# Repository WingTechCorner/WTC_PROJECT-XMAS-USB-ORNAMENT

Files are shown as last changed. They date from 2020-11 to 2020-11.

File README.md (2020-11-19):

# Wing's XMAS Ornament

** ISSUE - Design Seems To produce non-working unit. Investigating... **

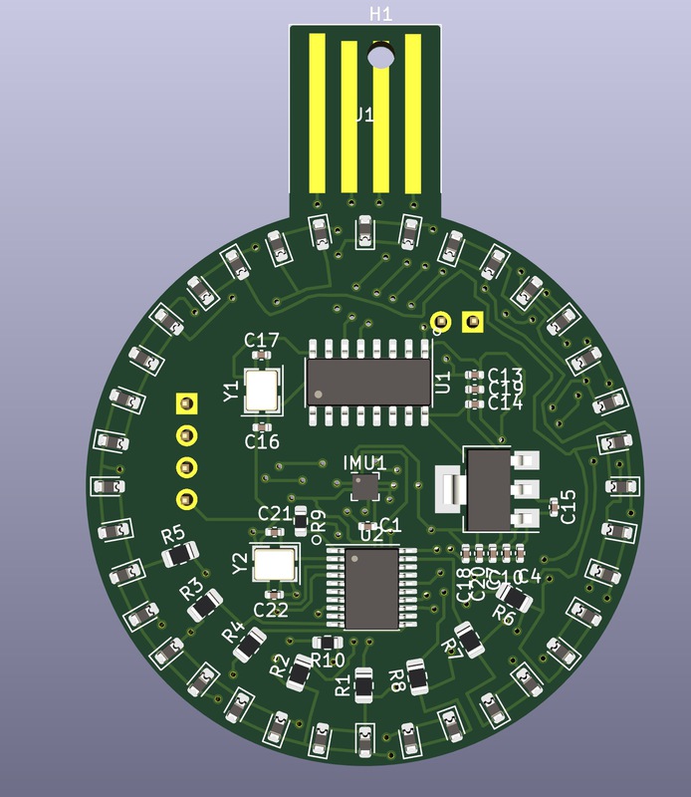
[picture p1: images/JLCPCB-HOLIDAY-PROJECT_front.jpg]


* Something for the holidays.
* Made using SMT/SMD components so most/all parts on one side.
* Added header pins on revrse side for adding batteries or different UART(s).
* Added USB-A PCB top to allow plugging into a laptop or computer USB port or to power with a USB-A extension cable.

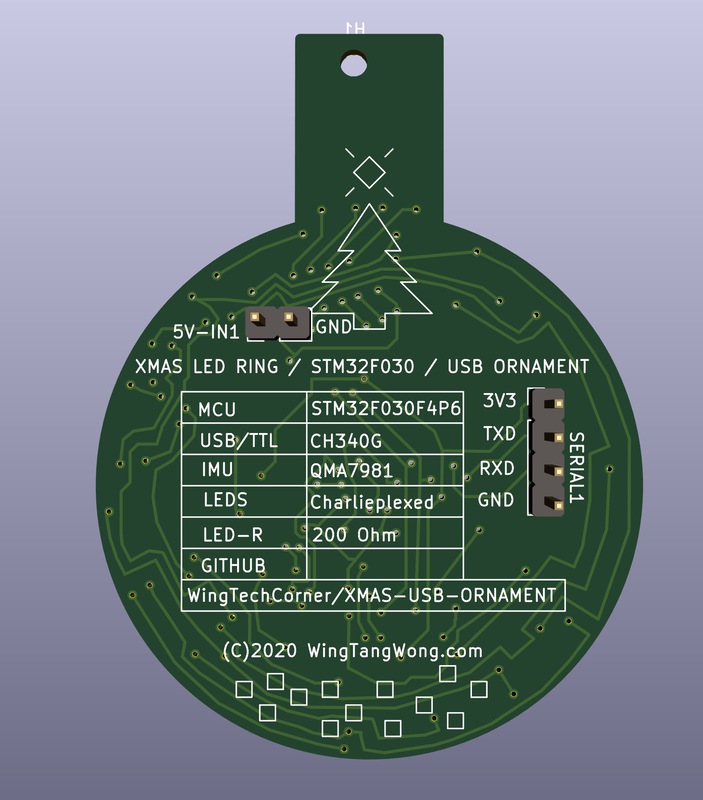
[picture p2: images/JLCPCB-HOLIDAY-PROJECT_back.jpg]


# JLCPCB Holiday Contest Entry

This is a project I'm also submitting to the [JLCPCB.com](http://www.jlcpcb.com) Holiday Contest!

* http://www.jlcpcb.com

# Hardware

## Components

* CH340G USB-to-TTL interface chip
* AMS1117-3v3 linear voltage regulator
* QMA7981 IMU in I2C mode
* STM32F030F4 - Arm M0 MCU

## STM32 

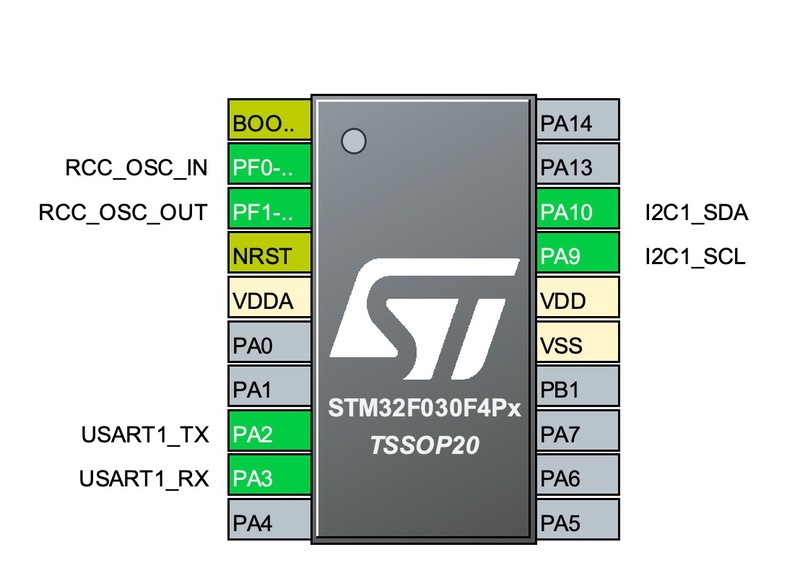
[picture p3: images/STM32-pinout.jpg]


* 12Mhz External OSC
* Boot0 - CH340G's CTS (pin 9) (pulldown via 4.7K, but can be brought HIGH by CH340G by toggling CTS)

### I2C 

* PA9  - I2C SCL (connects to QMA7981's SCL)
* PA10 - I2C SDA (connects to QMA7981's SDX)
* PB1  - Motion Interrupt Signal ( connects to QMA7981's INT2 )

### UART

* PA2  - UART-TX (connects to CH340G's RX)
* PA3  - UART-RD (connects to CH340G's TX)

### LED Driving Lines

* PA0  - A (CharliePlexed LED Lines)
* PA1  - B (CharliePlexed LED Lines)
* PA4  - C (CharliePlexed LED Lines)
* PA5  - D (CharliePlexed LED Lines)
* PA6  - E (CharliePlexed LED Lines)
* PA7  - F (CharliePlexed LED Lines)
* PA13 - G (CharliePlexed LED Lines)
* PA14 - H (CharliePlexed LED Lines)

## QMA7981

* AD0  - Sets address. Routed to GND for 0. 0x12H
* INT2 - Interrupt signal output. Routed to PB1 on MCU

## CH340G

* TXD  - To MCU RXD
* RXD  - To MCU TXD
* CTS  - To MCU BOOT0 for boot mode selector
* 12Mhz External OSC

# Software

## Building & Installing Arduino Code
The code is setup as a `platformio` project. To build:

```bash
# To compile/build
pio run

# To upload (Note, assumes serial upload)
pio run --target=upload
```

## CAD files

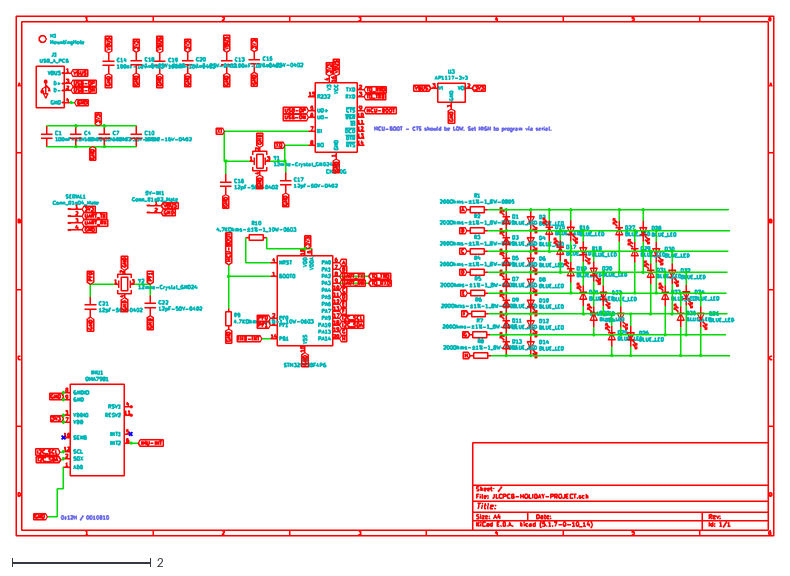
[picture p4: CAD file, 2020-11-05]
Hardware/JLCPCB-HOLIDAY-PROJECT.dxf
10.9 x 7.48

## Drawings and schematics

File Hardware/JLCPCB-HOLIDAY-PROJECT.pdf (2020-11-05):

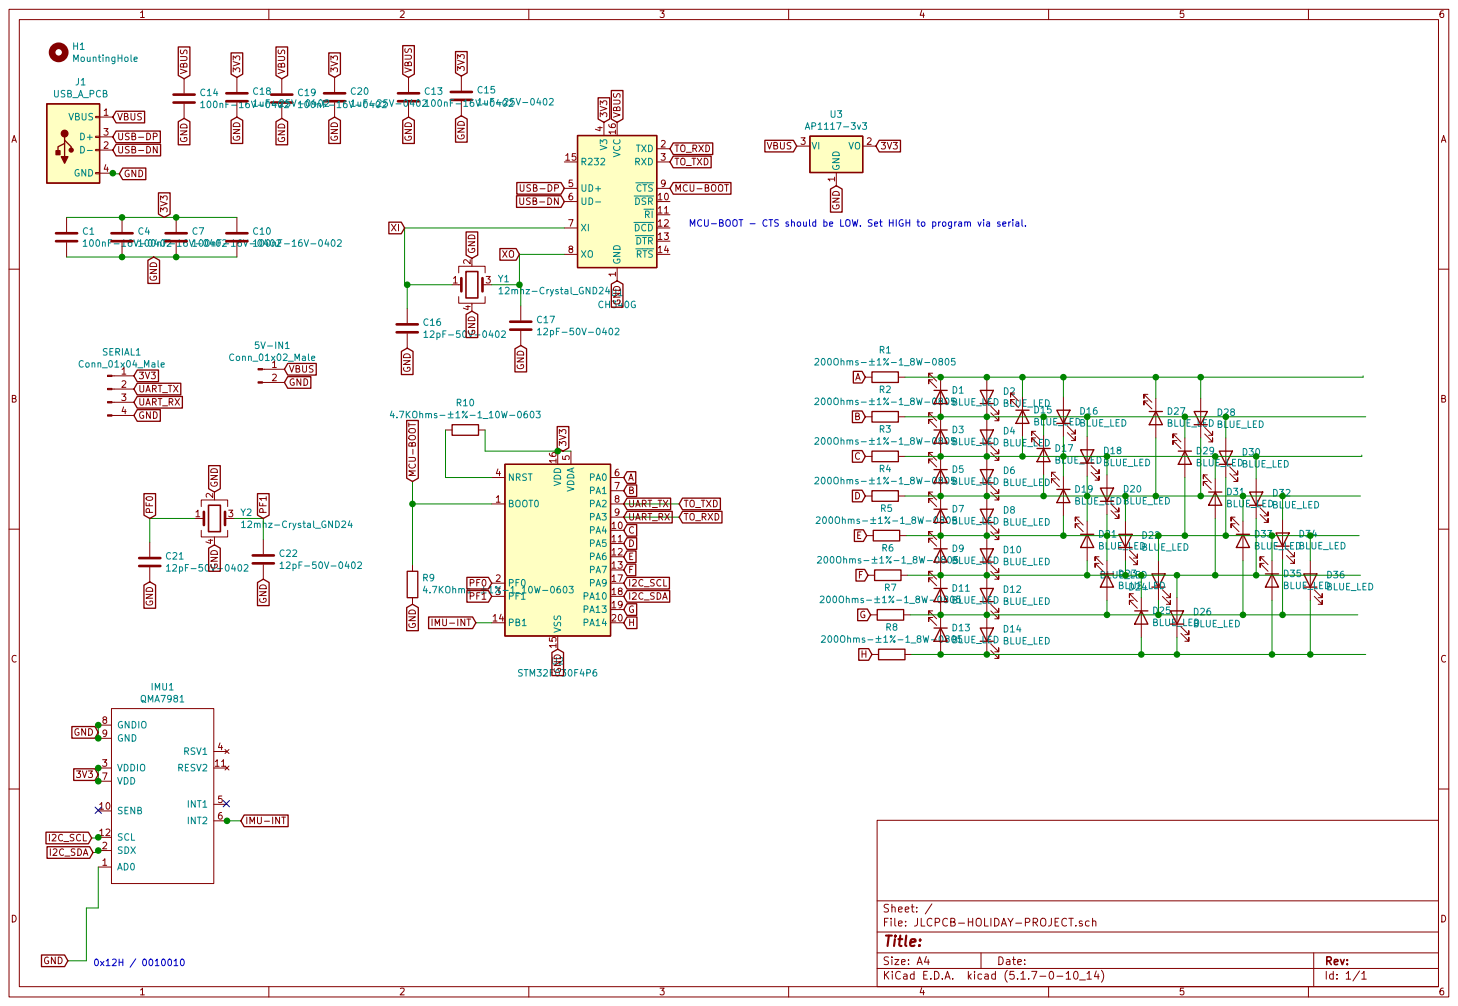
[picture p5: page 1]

1 DSR 10 RI 11 DCD 12 DTR 13 RTS 14 R232 15 VCC 16 TXD 2 RXD 3 V3

4 UD+ 5 UD- 6 XI 7 XO 8 CTS 9 U1 CH340G

MCU-BOOT - CTS should be LOW. Set HIGH to program via serial.

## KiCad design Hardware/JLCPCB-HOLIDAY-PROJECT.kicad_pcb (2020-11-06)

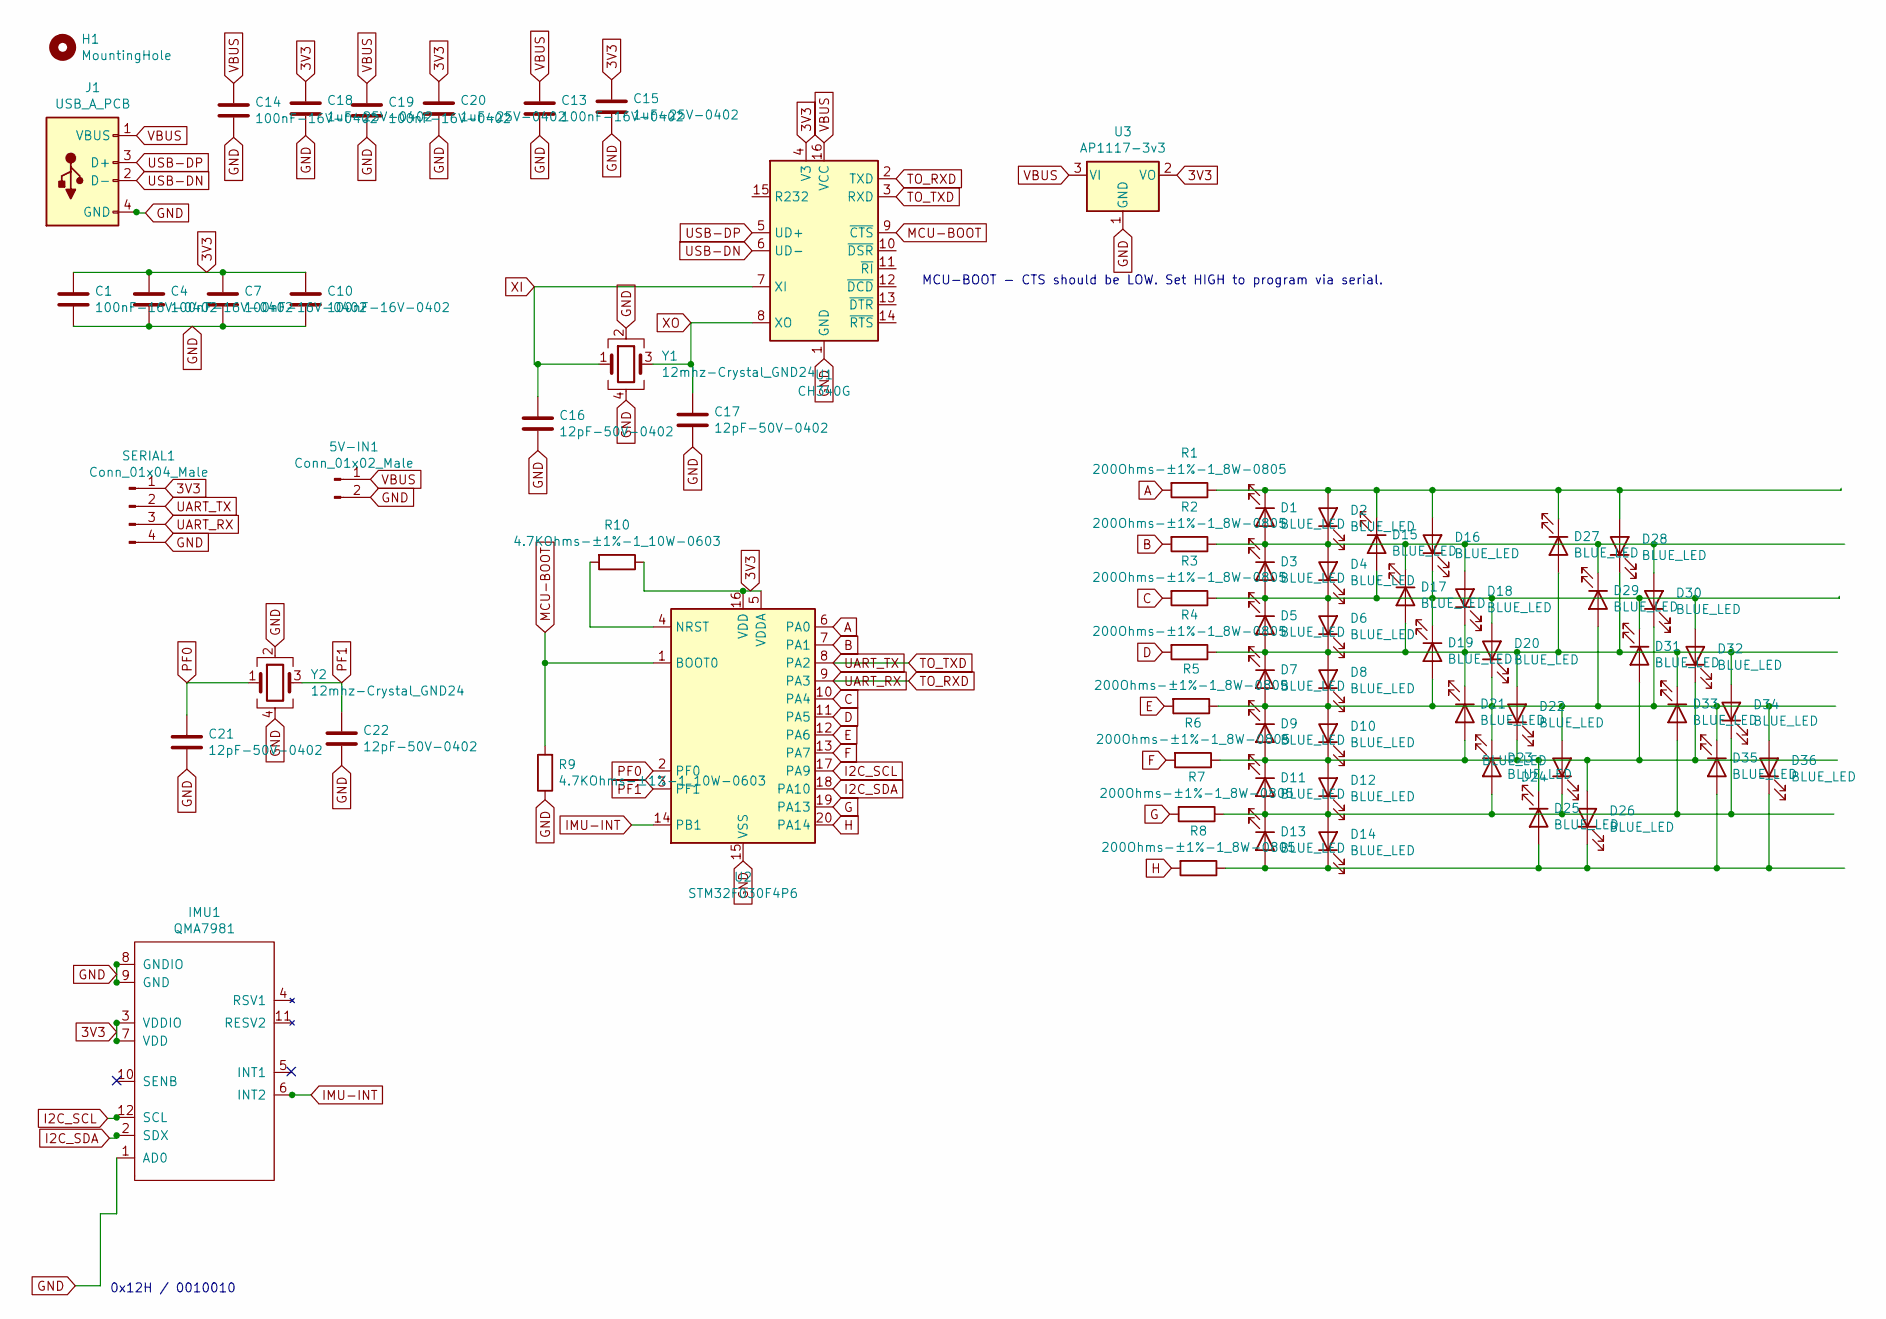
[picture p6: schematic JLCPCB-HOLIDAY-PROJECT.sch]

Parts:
5V-IN1: Conn_01x02_Male; PinHeader_1x02_P2.54mm_Vertical
C1, C4, C7, C10, C13, C14, C19: 100nF-16V-0402; C_0402_1005Metric; JLCPCB C1525
C15, C18, C20: 1uF-25V-0402; C_0402_1005Metric; JLCPCB C52923
C16, C17, C21, C22: 12pF-50V-0402; C_0402_1005Metric; JLCPCB C1547
D1, D2, D3, D4, D5, D6, D7, D8, D9, D10, D11, D12, D13, D14, D15, D16, D17, D18, D19, D20, D21, D22, D23, D24, D25, D26, D27, D28, D29, D30, D31, D32, D33, D34, D35, D36: BLUE_LED; D_0603_1608Metric; JLCPCB C72041
H1: MountingHole; MountingHole_2.2mm_M2
IMU1: QMA7981; LGA-12_2x2mm_P0.5mm; JLCPCBPART C457290
J1: USB_A_PCB; USB-A-PCB
R1, R2, R3, R4, R5, R6, R7, R8: 200Ohms-±1%-1_8W-0805; R_0805_2012Metric; JLCPCB C17540
R9, R10: 4.7KOhms-±1%-1_10W-0603; R_0603_1608Metric; JLCPCB C23162
SERIAL1: Conn_01x04_Male; PinHeader_1x04_P2.54mm_Vertical
U1: CH340G; SOIC-16_3.9x9.9mm_P1.27mm_JLC_ROTATED; JLCPCBPART C14267
U2: STM32F030F4P6; TSSOP-20_4.4x6.5mm_P0.65mm; JLCPCBPART C32908
U3: AP1117-3v3; SOT-223-3_TabPin2; JLCPCB C6186
Y1, Y2: 12mhz-Crystal_GND24; Crystal_SMD_TXC_7M-4Pin_3.2x2.5mm; JLCPCBPART C9002

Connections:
3V3: C1.1, C4.1, C7.1, C10.1, C15.1, C18.1, C20.1, IMU1.3 (VDDIO), IMU1.7 (VDD), R10.1, SERIAL1.1, U1.4 (V3), U2.5 (VDDA), U2.16 (VDD), U3.2 (VO)
A: R1.2, U2.6 (PA0)
B: R2.2, U2.7 (PA1)
C: R3.2, U2.10 (PA4)
D: R4.2, U2.11 (PA5)
E: R5.2, U2.12 (PA6)
F: R6.2, U2.13 (PA7)
G: R7.2, U2.19 (PA13)
GND: 5V-IN1.2, C1.2, C4.2, C7.2, C10.2, C13.2, C14.2, C15.2, C16.2, C17.2, C18.2, C19.2, C20.2, C21.2, C22.2, IMU1.1 (AD0), IMU1.8 (GNDIO), IMU1.9 (GND), J1.4 (GND), R9.1, SERIAL1.4, U1.1 (GND), U2.15 (VSS), U3.1 (GND), Y1.2, Y1.4, Y2.2, Y2.4
H: R8.2, U2.20 (PA14)
I2C_SCL: IMU1.12 (SCL), U2.17 (PA9)
I2C_SDA: IMU1.2 (SDX), U2.18 (PA10)
IMU-INT: IMU1.6 (INT2), U2.14 (PB1)
MCU-BOOT: R9.2, U1.9 (~CTS), U2.1 (BOOT0)
unnamed: D1.1 (K), D2.2 (A), D15.1 (K), D16.2 (A), D27.1 (K), D28.2 (A), R1.1
unnamed: D1.2 (A), D2.1 (K), D3.1 (K), D4.2 (A), D17.1 (K), D18.2 (A), D29.1 (K), D30.2 (A), R2.1
unnamed: D9.2 (A), D10.1 (K), D11.1 (K), D12.2 (A), D21.2 (A), D22.1 (K), D25.1 (K), D26.2 (A), D31.2 (A), D32.1 (K), R6.1
unnamed: D7.2 (A), D8.1 (K), D9.1 (K), D10.2 (A), D19.2 (A), D20.1 (K), D23.1 (K), D24.2 (A), D29.2 (A), D30.1 (K), D35.1 (K), D36.2 (A), R5.1
unnamed: D11.2 (A), D12.1 (K), D13.1 (K), D14.2 (A), D23.2 (A), D24.1 (K), D33.2 (A), D34.1 (K), R7.1
unnamed: D13.2 (A), D14.1 (K), D25.2 (A), D26.1 (K), D35.2 (A), D36.1 (K), R8.1
unnamed: D3.2 (A), D4.1 (K), D5.1 (K), D6.2 (A), D15.2 (A), D16.1 (K), D19.1 (K), D20.2 (A), D31.1 (K), D32.2 (A), R3.1
unnamed: D5.2 (A), D6.1 (K), D7.1 (K), D8.2 (A), D17.2 (A), D18.1 (K), D21.1 (K), D22.2 (A), D27.2 (A), D28.1 (K), D33.1 (K), D34.2 (A), R4.1
unnamed: R10.2, U2.4 (NRST)
PF0: C21.1, U2.2 (PF0), Y2.1
PF1: C22.1, U2.3 (PF1), Y2.3
TO_RXD: SERIAL1.3, U1.2 (TXD), U2.9 (PA3)
TO_TXD: SERIAL1.2, U1.3 (RXD), U2.8 (PA2)
USB-DN: J1.2 (D-), U1.6 (UD-)
USB-DP: J1.3 (D+), U1.5 (UD+)
VBUS: 5V-IN1.1, C13.1, C14.1, C19.1, J1.1 (VBUS), U1.16 (VCC), U3.3 (VI)
XI: C16.1, U1.7 (XI), Y1.1
XO: C17.1, U1.8 (XO), Y1.3

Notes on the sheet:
MCU-BOOT - CTS should be LOW. Set HIGH to program via serial.
0x12H / 0010010

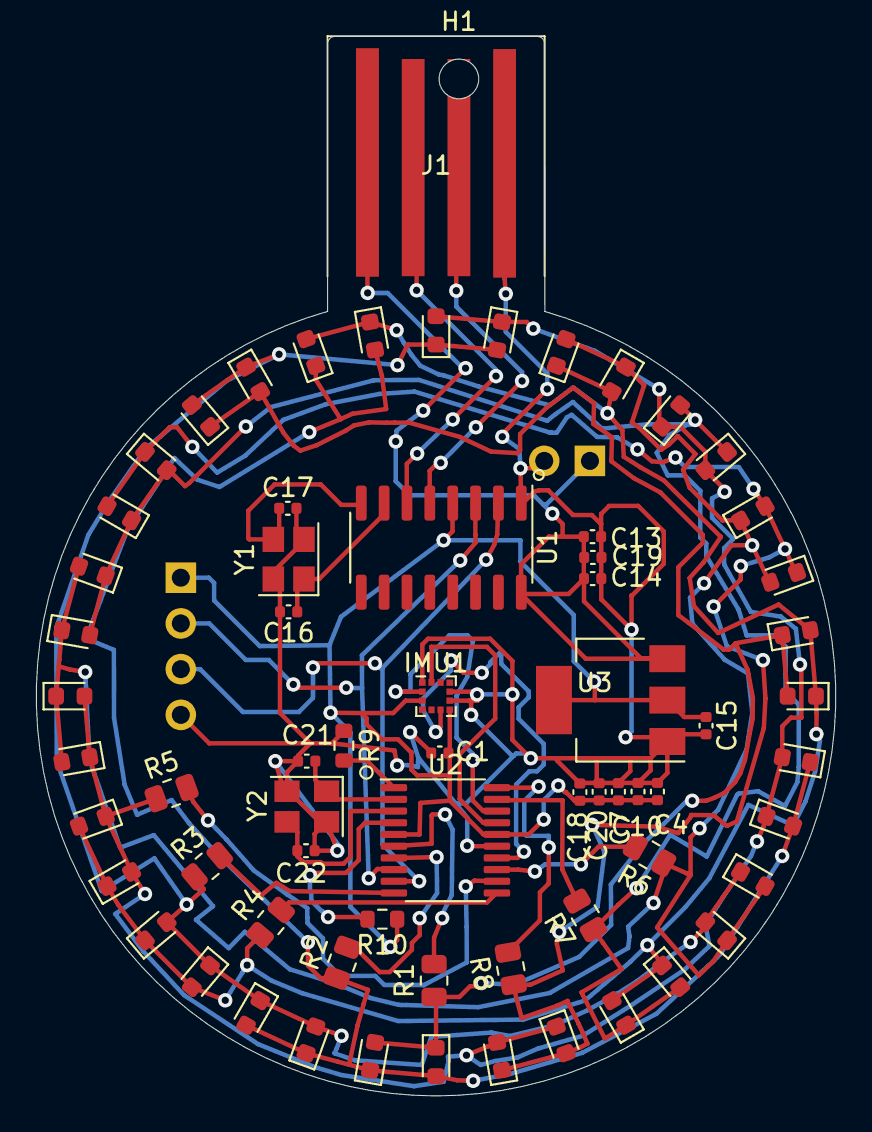
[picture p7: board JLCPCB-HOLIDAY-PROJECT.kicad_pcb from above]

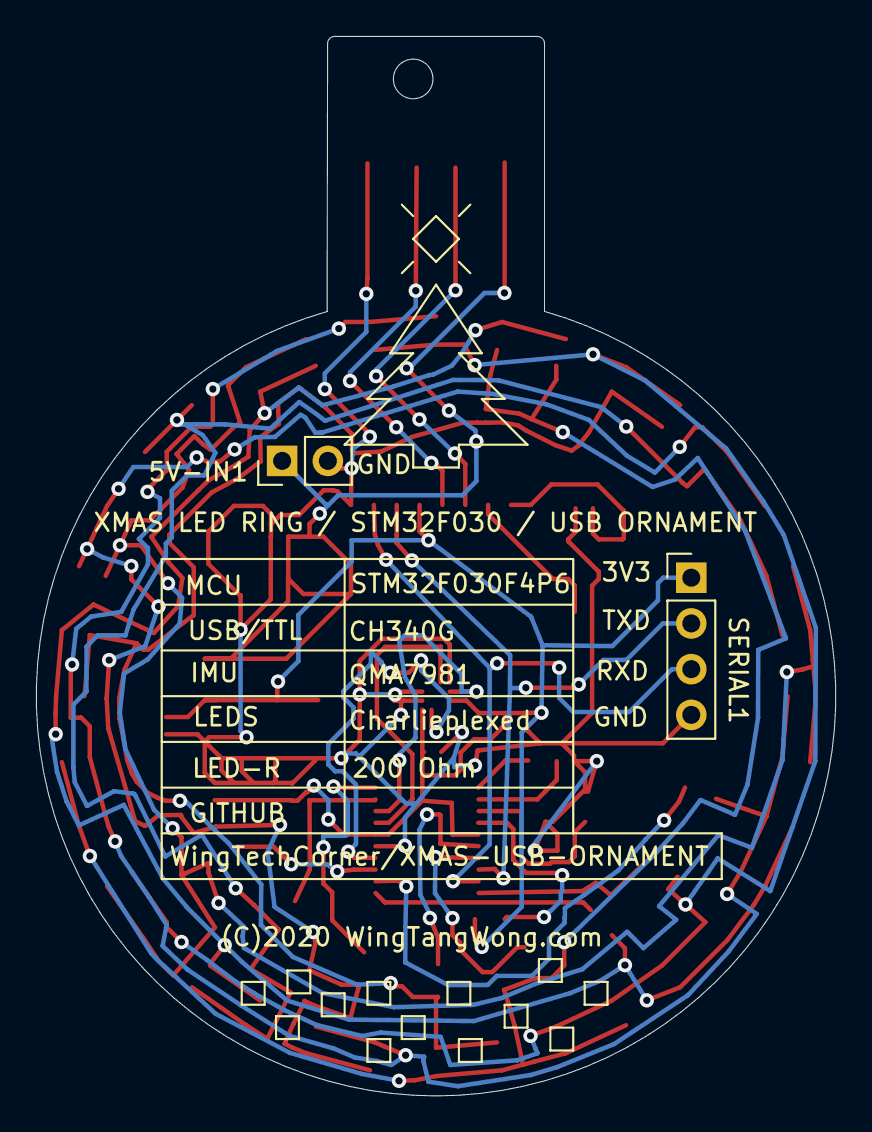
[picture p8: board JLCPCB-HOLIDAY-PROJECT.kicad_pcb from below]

Board: 2 copper layers, 44.4 x 58.9 mm, 70 parts (2 on the bottom side), 32 nets.

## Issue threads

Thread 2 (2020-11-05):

compile fail...

WingTechCorner, 2020-11-05:

WingTechCorner, 2020-11-06:
Closing. Fixed.

Closed 2020-11-06.

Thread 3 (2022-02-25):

What is the IMU used for?

mahboud, 2022-02-25:
This looks really cool. Thanks for sharing it, and I do see it might have issues.

I'm curious what you were going to do with the IMU.

BTW, did you find this IMU easy to work with? I have experience only with the 6050 and the 6886.

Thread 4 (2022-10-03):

Schematic confirmed to be working?

glowingkitty, 2022-10-03:
Hey there,
I found your schematic while searching for examples of projects using the QMA7981. Can you confirm that the gyroscope works correctly the way you implemented it? If so, I guess I need to update my schematic, where I connect the QMA7981 to an ESP32 WROOM 32E.

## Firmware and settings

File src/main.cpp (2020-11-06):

/* ==================== ==================== ==================== ==================== 
 *  Wing Tang Wong's XMAS USB ORNAMENT Lighting Program
 *  ©2020 Wing Tang Wong
 * ==================== ==================== ==================== ==================== 
 *
 *  Code to control the hardware design of STM32F030F4 
 *  attached to 36 LED(s) in a charlieplexed configuration.
 *
 *  Communication with the MCU can be done via:
 *  - 4 pin UART header
 *  - USB serial via onboard CH340G
 *
 *  Power can be supplied via:
 *  - USB 5V
 *  - 5-12V via 2 pin
 *  - 3v3 via UART header
 *
 */

/* ==================== ==================== ==================== ==================== 
 *  Basic Arduino Boilerplate and libraries
 * ==================== ==================== ==================== ==================== 
 *
 * - Arduino.h  For basic Arduino stuff
 * - Wire.h     Mainly for I2C communication with the QMA7981 IMU
 *
 *
 */
#include <Arduino.h>
#include <Wire.h>

/* ==================== ==================== ==================== ==================== 
 * Global States of LED(s)
 * ==================== ==================== ==================== ==================== 
 * All default to zero
 * 0 = OFF
 * 128 = MAX ON
 */
uint8_t LED_STATE[36] = {0,0,0,0,0,0,0,0,0,0,0,0,0,0,0,0,0,0,0,0,0,0,0,0,0,0,0,0,0,0,0,0,0,0,0,0};
uint8_t LED_COUNTER[36] = {0,0,0,0,0,0,0,0,0,0,0,0,0,0,0,0,0,0,0,0,0,0,0,0,0,0,0,0,0,0,0,0,0,0,0,0};

/* ==================== ==================== ==================== ==================== 
 * Mapping pins of STM32 to rows
 * ==================== ==================== ==================== ==================== 
 *
 * PA0 - A (CharliePlexed LED Lines)
 * PA1 - B (CharliePlexed LED Lines)
 * PA4 - C (CharliePlexed LED Lines)
 * PA5 - D (CharliePlexed LED Lines)
 * PA6 - E (CharliePlexed LED Lines)
 * PA7 - F (CharliePlexed LED Lines)
 * PA13 - G (CharliePlexed LED Lines)
 * PA14 - H (CharliePlexed LED Lines)
 */
uint8_t ROW_PIN[8] = { PA0, PA1, PA4, PA5, PA6, PA7, PA13, PA14 };


/*
 * ==================== ==================== ==================== ==================== 
 * Charlie Plexing Map for LED1 through LED36
 * ==================== ==================== ==================== ==================== 
 *
 * 0 = LOW
 * 1 = HIGH
 * x = DONT CARE
 *
 * For LED(s) that do not conflict with one
 * another, it should be possible to light up
 * more than one LED at a time.
 *
 * D1  = A1, B0 , Cx , Dx , Ex , Fx , Gx , Hx
 * D2  = A0, B1 , Cx , Dx , Ex , Fx , Gx , Hx
 * D3  = Ax, B0 , C1 , Dx , Ex , Fx , Gx , Hx
 * D4  = Ax, B1 , C0 , Dx , Ex , Fx , Gx , Hx
 * D5  = Ax, Bx , C0 , D1 , Ex , Fx , Gx , Hx
 * D6  = Ax, Bx , C1 , D0 , Ex , Fx , Gx , Hx
 * D7  = Ax, Bx , Cx , D0 , E1 , Fx , Gx , Hx
 * D8  = Ax, Bx , Cx , D1 , E0 , Fx , Gx , Hx
 * D9  = Ax, Bx , Cx , Dx , E0 , F1 , Gx , Hx
 * D10 = Ax, Bx , Cx , Dx , E1 , F0 , Gx , Hx
 * D11 = Ax, Bx , Cx , Dx , Ex , F0 , G1 , Hx
 * D12 = Ax, Bx , Cx , Dx , Ex , F1 , G0 , Hx
 * D13 = Ax, Bx , Cx , Dx , Ex , Fx , G0 , H1
 * D14 = Ax, Bx , Cx , Dx , Ex , Fx , G1 , H0
 *
 * D15 = A0, Bx , C1 , Dx , Ex , Fx , Gx , Hx
 * D16 = A1, Bx , C0 , Dx , Ex , Fx , Gx , Hx
 * D17 = Ax, B0 , Cx , D1 , Ex , Fx , Gx , Hx
 * D18 = Ax, B1 , Cx , D0 , Ex , Fx , Gx , Hx
 * D19 = Ax, Bx , C0 , Dx , E1 , Fx , Gx , Hx
 * D20 = Ax, Bx , C1 , Dx , E0 , Fx , Gx , Hx
 * D21 = Ax, Bx , Cx , D0 , Ex , F1 , Gx , Hx
 * D22 = Ax, Bx , Cx , D1 , Ex , F0 , Gx , Hx
 * D23 = Ax, Bx , Cx , Dx , E0 , Fx , G1 , Hx
 * D24 = Ax, Bx , Cx , Dx , E1 , Fx , G0 , Hx
 * D25 = Ax, Bx , Cx , Dx , Ex , F0 , Gx , H1
 * D26 = Ax, Bx , Cx , Dx , Ex , F1 , Gx , H0
 *
 * D27 = A0, Bx , Cx , D1 , Ex , Fx , Gx , Hx
 * D28 = A1, Bx , Cx , D0 , Ex , Fx , Gx , Hx
 * D29 = Ax, B0 , Cx , Dx , E1 , Fx , Gx , Hx
 * D30 = Ax, B1 , Cx , Dx , E0 , Fx , Gx , Hx
 * D31 = Ax, Bx , C0 , Dx , Ex , F1 , Gx , Hx
 * D32 = Ax, Bx , C1 , Dx , Ex , F0 , Gx , Hx
 * D33 = Ax, Bx , Cx , D0 , Ex , Fx , G1 , Hx
 * D34 = Ax, Bx , Cx , D1 , Ex , Fx , G0 , Hx
 * D35 = Ax, Bx , Cx , Dx , E0 , Fx , Gx , H1
 * D36 = Ax, Bx , Cx , Dx , E1 , Fx , Gx , H0
 *
 */
uint8_t LED_PINS[36][8] = {
  { 1, 0 , 0 , 0 , 0 , 0 , 0 , 0 },
  { 0, 1 , 0 , 0 , 0 , 0 , 0 , 0 },
  { 0, 0 , 1 , 0 , 0 , 0 , 0 , 0 },
  { 0, 1 , 0 , 0 , 0 , 0 , 0 , 0 },
  { 0, 0 , 0 , 1 , 0 , 0 , 0 , 0 },
  { 0, 0 , 1 , 0 , 0 , 0 , 0 , 0 },
  { 0, 0 , 0 , 0 , 1 , 0 , 0 , 0 },
  { 0, 0 , 0 , 1 , 0 , 0 , 0 , 0 },
  { 0, 0 , 0 , 0 , 0 , 1 , 0 , 0 },
  { 0, 0 , 0 , 0 , 1 , 0 , 0 , 0 },
  { 0, 0 , 0 , 0 , 0 , 0 , 1 , 0 },
  { 0, 0 , 0 , 0 , 0 , 1 , 0 , 0 },
  { 0, 0 , 0 , 0 , 0 , 0 , 0 , 1 },
  { 0, 0 , 0 , 0 , 0 , 0 , 1 , 0 },
  { 0, 0 , 1 , 0 , 0 , 0 , 0 , 0 },
  { 1, 0 , 0 , 0 , 0 , 0 , 0 , 0 },
  { 0, 0 , 0 , 1 , 0 , 0 , 0 , 0 },
  { 0, 1 , 0 , 0 , 0 , 0 , 0 , 0 },
  { 0, 0 , 0 , 0 , 1 , 0 , 0 , 0 },
  { 0, 0 , 1 , 0 , 0 , 0 , 0 , 0 },
  { 0, 0 , 0 , 0 , 0 , 1 , 0 , 0 },
  { 0, 0 , 0 , 1 , 0 , 0 , 0 , 0 },
  { 0, 0 , 0 , 0 , 0 , 0 , 1 , 0 },
  { 0, 0 , 0 , 0 , 1 , 0 , 0 , 0 },
  { 0, 0 , 0 , 0 , 0 , 0 , 0 , 1 },
  { 0, 0 , 0 , 0 , 0 , 1 , 0 , 0 },
  { 0, 0 , 0 , 1 , 0 , 0 , 0 , 0 },
  { 1, 0 , 0 , 0 , 0 , 0 , 0 , 0 },
  { 0, 0 , 0 , 0 , 1 , 0 , 0 , 0 },
  { 0, 1 , 0 , 0 , 0 , 0 , 0 , 0 },
  { 0, 0 , 0 , 0 , 0 , 1 , 0 , 0 },
  { 0, 0 , 1 , 0 , 0 , 0 , 0 , 0 },
  { 0, 0 , 0 , 0 , 0 , 0 , 1 , 0 },
  { 0, 0 , 0 , 1 , 0 , 0 , 0 , 0 },
  { 0, 0 , 0 , 0 , 0 , 0 , 0 , 1 },
  { 0, 0 , 0 , 0 , 1 , 0 , 0 , 0 } 
};




/* 
 * ==================== ==================== ==================== ==================== 
 * Interrupt related variables. 
 * - Interrupt line is from the IMU
 * ==================== ==================== ==================== ==================== 
 */

uint8_t imuPIN = PB1;
volatile int imuSTATE = LOW;

/* 
 * ==================== ==================== ==================== ==================== 
 * Various variables For main application
 * ==================== ==================== ==================== ==================== 
 */

uint32_t ts_delta =0;
uint32_t ts_tick  =5000;
uint32_t ts_last  =0;
uint32_t ts_curr  =0;
uint8_t  active_led = 0;

/* 
 * ==================== ==================== ==================== ==================== 
 * Function declarations
 *
 * Sane folks probably just put this all into a 'main.h' file.... >_>
 * ==================== ==================== ==================== ==================== 
 */

void LED_ON( uint8_t led );
void LED_OFF( uint8_t led);
void LED_SET( uint8_t led, uint8_t val );
void DISPLAY_LED(uint8_t led);
void LED_DISPLAY();
void LED_TICK();
void IMU_SERVICE_UP();
void IMU_SERVICE_DOWN();


/* 
 * ==================== ==================== ==================== ==================== 
 * Setup
 * ==================== ==================== ==================== ==================== 
 */
void setup() {
  // Setup an interrupt for the IMU (PB1)
  //
  attachInterrupt(digitalPinToInterrupt(imuPIN),IMU_SERVICE_UP,RISING);
  attachInterrupt(digitalPinToInterrupt(imuPIN),IMU_SERVICE_DOWN,FALLING);

  // Load up some values for the interval timers
  ts_last=micros();
  ts_curr=micros();
  ts_delta=ts_curr - ts_last;
};

/* 
 * ==================== ==================== ==================== ==================== 
 * Main Loop
 * ==================== ==================== ==================== ==================== 
 */

void loop() {
  ts_curr=micros();

  // After a duration of ts_tick, update which LED gets lit
  if ( ( ts_curr - ts_last ) > ts_tick ) {
    ts_last = ts_curr;    
    LED_OFF(active_led);
    active_led += 1;
    LED_ON(active_led);
  };

  LED_TICK();
  LED_DISPLAY();
};

/* 
 * ==================== ==================== ==================== ==================== 
 * functions to set LED state
 * ==================== ==================== ==================== ==================== 
 *
 * General idea... the value assigned to the state of the LED is the target that needs
 * to be hit to shut the light off.
 *
 * However, only one light should ever be on at one time. 
 */

void LED_ON( uint8_t led) {
  LED_STATE[led]=128;  
};

void LED_OFF( uint8_t led){
  LED_STATE[led]=0;
};

void LED_SET( uint8_t led, uint8_t val = 128) {
  if ( val >= 128 ) {
    LED_STATE[led]=128;
  } else {
    LED_STATE[led]=val;
  };
};

void LED_TICK() {
  for( uint8_t i=0; i<36; i++ ) {
    LED_COUNTER[i] += 1;
    if ( LED_COUNTER[i] > LED_STATE[i] ) { LED_COUNTER[i]=0; };
  };
};

void DISPLAY_LED(uint8_t led = 0) {
  if ( led < 36 ) {
    for( uint8_t row = 0; row < 8; row++ ) {
      digitalWrite( ROW_PIN[row], LED_PINS[led][row] );
    };
  }; 
};


void LED_DISPLAY() {
  for( uint8_t i=0; i<36; i++ ) {
    if ( LED_COUNTER[i] <= LED_STATE[i] ) {
      DISPLAY_LED(i);
    };
  };
};


/* 
 * ==================== ==================== ==================== ==================== 
 * ISR Handling Function from IMU
 * ==================== ==================== ==================== ==================== 
 */
void IMU_SERVICE_UP() {
  imuSTATE = HIGH;
};

void IMU_SERVICE_DOWN() {
  imuSTATE = LOW;
};

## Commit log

2020-11-04 80% of the way done
    [JLCPCB-HOLIDAY-PROJECT.kicad_pcb, JLCPCB-HOLIDAY-PROJECT.sch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]
2020-11-04 Adding silkscreen text on back
2020-11-04 Added more text notes
    [JLCPCB-HOLIDAY-PROJECT.kicad_pcb]
2020-11-05 Updated traces to add interrupt return, address set to 0, and boot/nrst for the mcu
    [JLCPCB-HOLIDAY-PROJECT.kicad_pcb, JLCPCB-HOLIDAY-PROJECT.sch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]
2020-11-05 Update Adding mention that this is being submitted for the JLCPCB Holiday Contest Update README.md Added images Resized jpeg Updated readme Moving HW files into Hardware. Adding Platform IO bits for 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
    [JLCPCB-HOLIDAY-PROJECT.dxf, JLCPCB-HOLIDAY-PROJECT.kicad_pcb, JLCPCB-HOLIDAY-PROJECT.sch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]
2020-11-06 Added more routines for handling LED state counting, displaying LED(s), and putting the rows/pins into an array for easy referening.
    [JLCPCB-HOLIDAY-PROJECT.kicad_pcb]
2020-11-06 Updated interrupt into separate up and down functions.
2020-11-06 Added STM32 pinouts and updated README.me
2020-11-06 Added a simple loop to increment through the LED(s) turning off the previous LED.
2020-11-19 Found error with board. Don't use yet.

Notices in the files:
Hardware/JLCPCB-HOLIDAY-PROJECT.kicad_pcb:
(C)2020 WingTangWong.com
